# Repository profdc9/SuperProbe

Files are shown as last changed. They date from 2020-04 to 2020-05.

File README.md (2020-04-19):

This is a KiCad implementation of Carlson's Superprobe by Daniel L. Marks, KW4TI.

It integrates the probe into the PCB by using the ground plane and vias to shield the probe.  The solder mask is left off of the area around the probe so that the probe can be taped over with copper or aluminum tape for extra shielding.

The PCB design is distributed under the Creative Commons Shared Alike Attribution (CC-BY-SA 4.0) license.

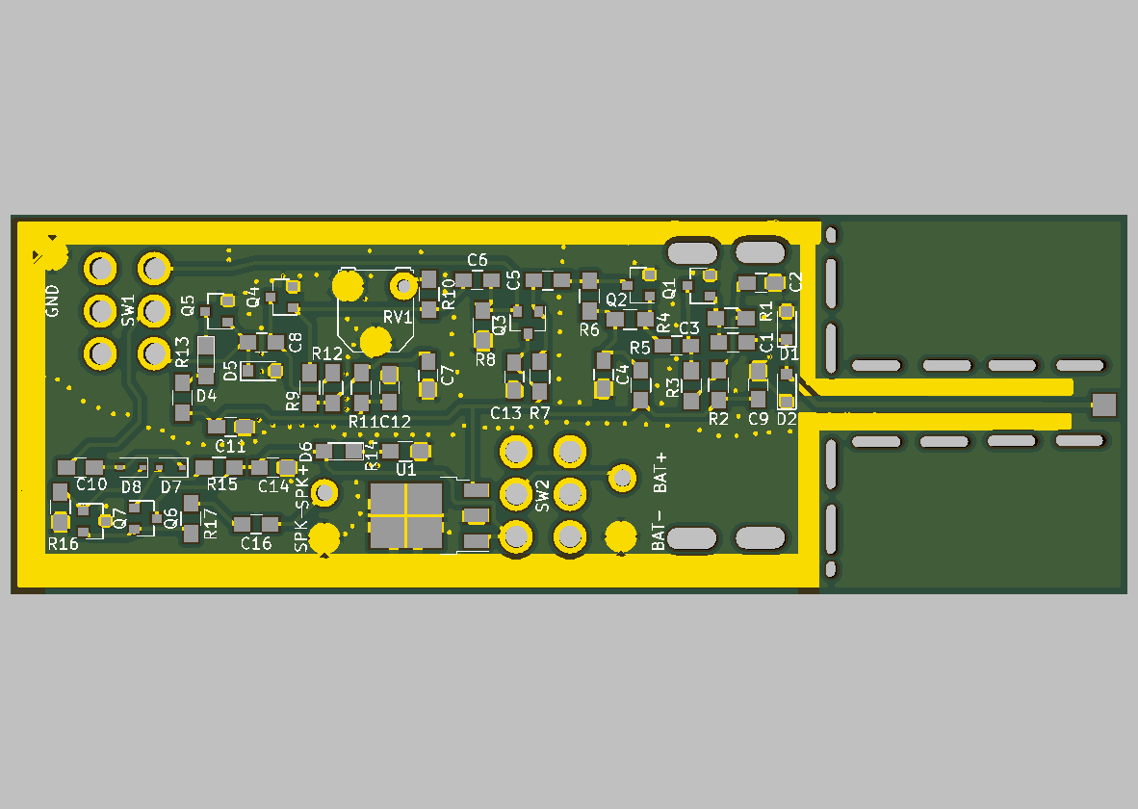
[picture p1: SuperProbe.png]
x


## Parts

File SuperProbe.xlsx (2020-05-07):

Comment | Designator | Footprint | LCSC
10 nF | C1,C3 | Capacitors_SMD:C_0805_HandSoldering | C1710
22 uF | C2,C4,C7,C16 | Capacitors_SMD:C_0805_HandSoldering | C45783
100 nF | C5,C6,C10 | Capacitors_SMD:C_0805_HandSoldering | C49678
330 pF | C8 | Capacitors_SMD:C_0805_HandSoldering | C51207
1 uF | C9,C12,C13,C11,C14 | Capacitors_SMD:C_0805_HandSoldering | C28323
1N4148WS | D1,D2 | Diodes_SMD:D_SOD-323_HandSoldering | C2128
LRB751V | D3,D5 | Diodes_SMD:D_SOD-323_HandSoldering | C131730
LED | D4,D6 | LEDs:LED_0805_HandSoldering | C34499
1N4148WS | D7,D8 | Diodes_SMD:D_SOD-323 | C2128
Conn_01x01 | J1,J16,J18,J19,J17,J24 | SuperProbe:PadHole
Conn_01x01 | J2,J3,J6,J7,J4,J5,J8,J9,J10,J11,J14,J15,J12,J13,J20,J21,J23,J22 | SuperProbe:BigSlot
MMBT3904 | Q1,Q2,Q3,Q4,Q5 | TO_SOT_Packages_SMD:SOT-23 | C20526
SS8050 | Q6 | TO_SOT_Packages_SMD:SOT-23 | C2150
SS8550 | Q7 | TO_SOT_Packages_SMD:SOT-23 | C8542
2M2 | R1,R4,R7,R9 | Resistors_SMD:R_0805_HandSoldering | C26113
330k | R10 | Resistors_SMD:R_0805_HandSoldering | C17629
10k | R16,R15 | Resistors_SMD:R_0805_HandSoldering | C17414
47R | R17 | Resistors_SMD:R_0805_HandSoldering | C17714
1k | R2,R5,R11,R13,R14 | Resistors_SMD:R_0805_HandSoldering | C17513
15k | R3,R6,R12 | Resistors_SMD:R_0805_HandSoldering | C17475
2k7 | R8 | Resistors_SMD:R_0805_HandSoldering | C17530
100k | RV1 | Potentiometers:Potentiometer_Triwood_RM-065
SW_SPDT | SW1 | SuperProbe:DPDTsmallswitch
SW_DPDT_x2 | SW2 | SuperProbe:DPDTsmallswitch
LM78M05_TO252 | U1 | TO_SOT_Packages_SMD:TO-252-3_TabPin2 | C58069

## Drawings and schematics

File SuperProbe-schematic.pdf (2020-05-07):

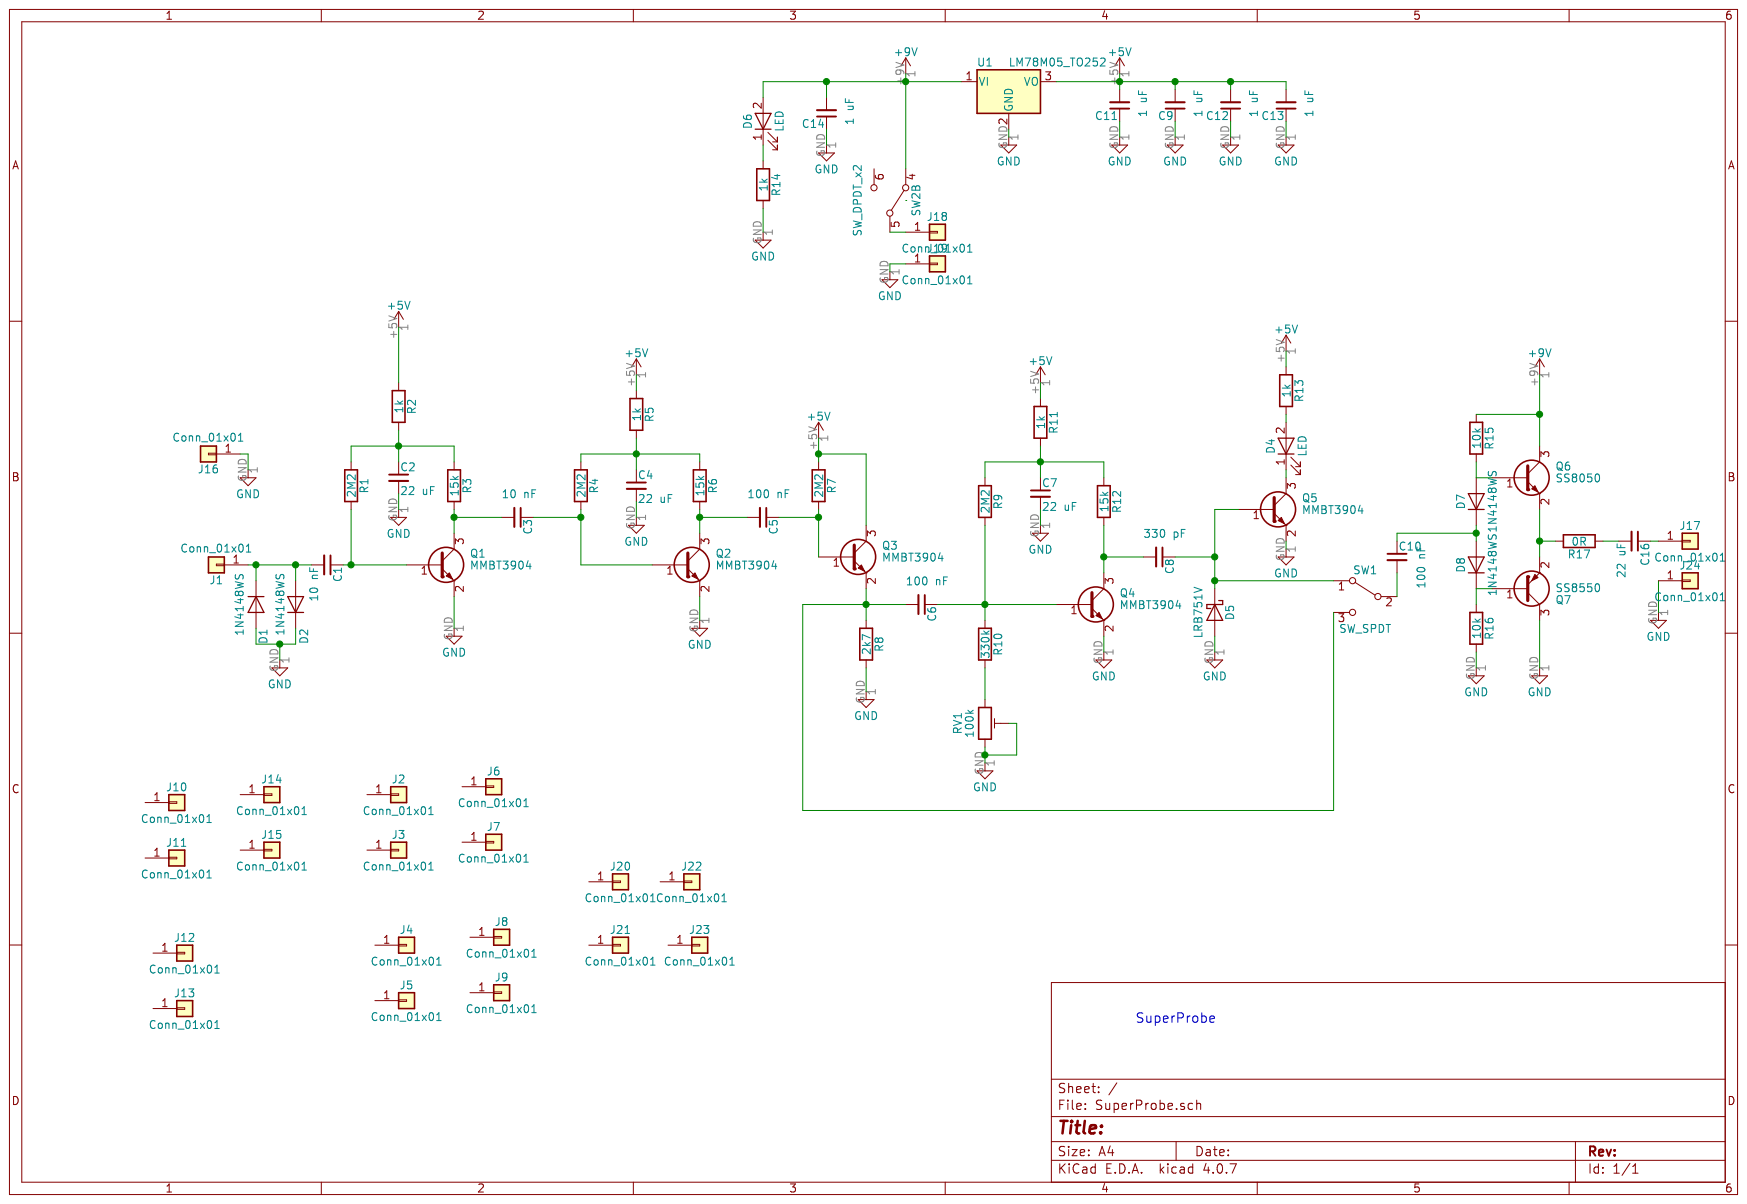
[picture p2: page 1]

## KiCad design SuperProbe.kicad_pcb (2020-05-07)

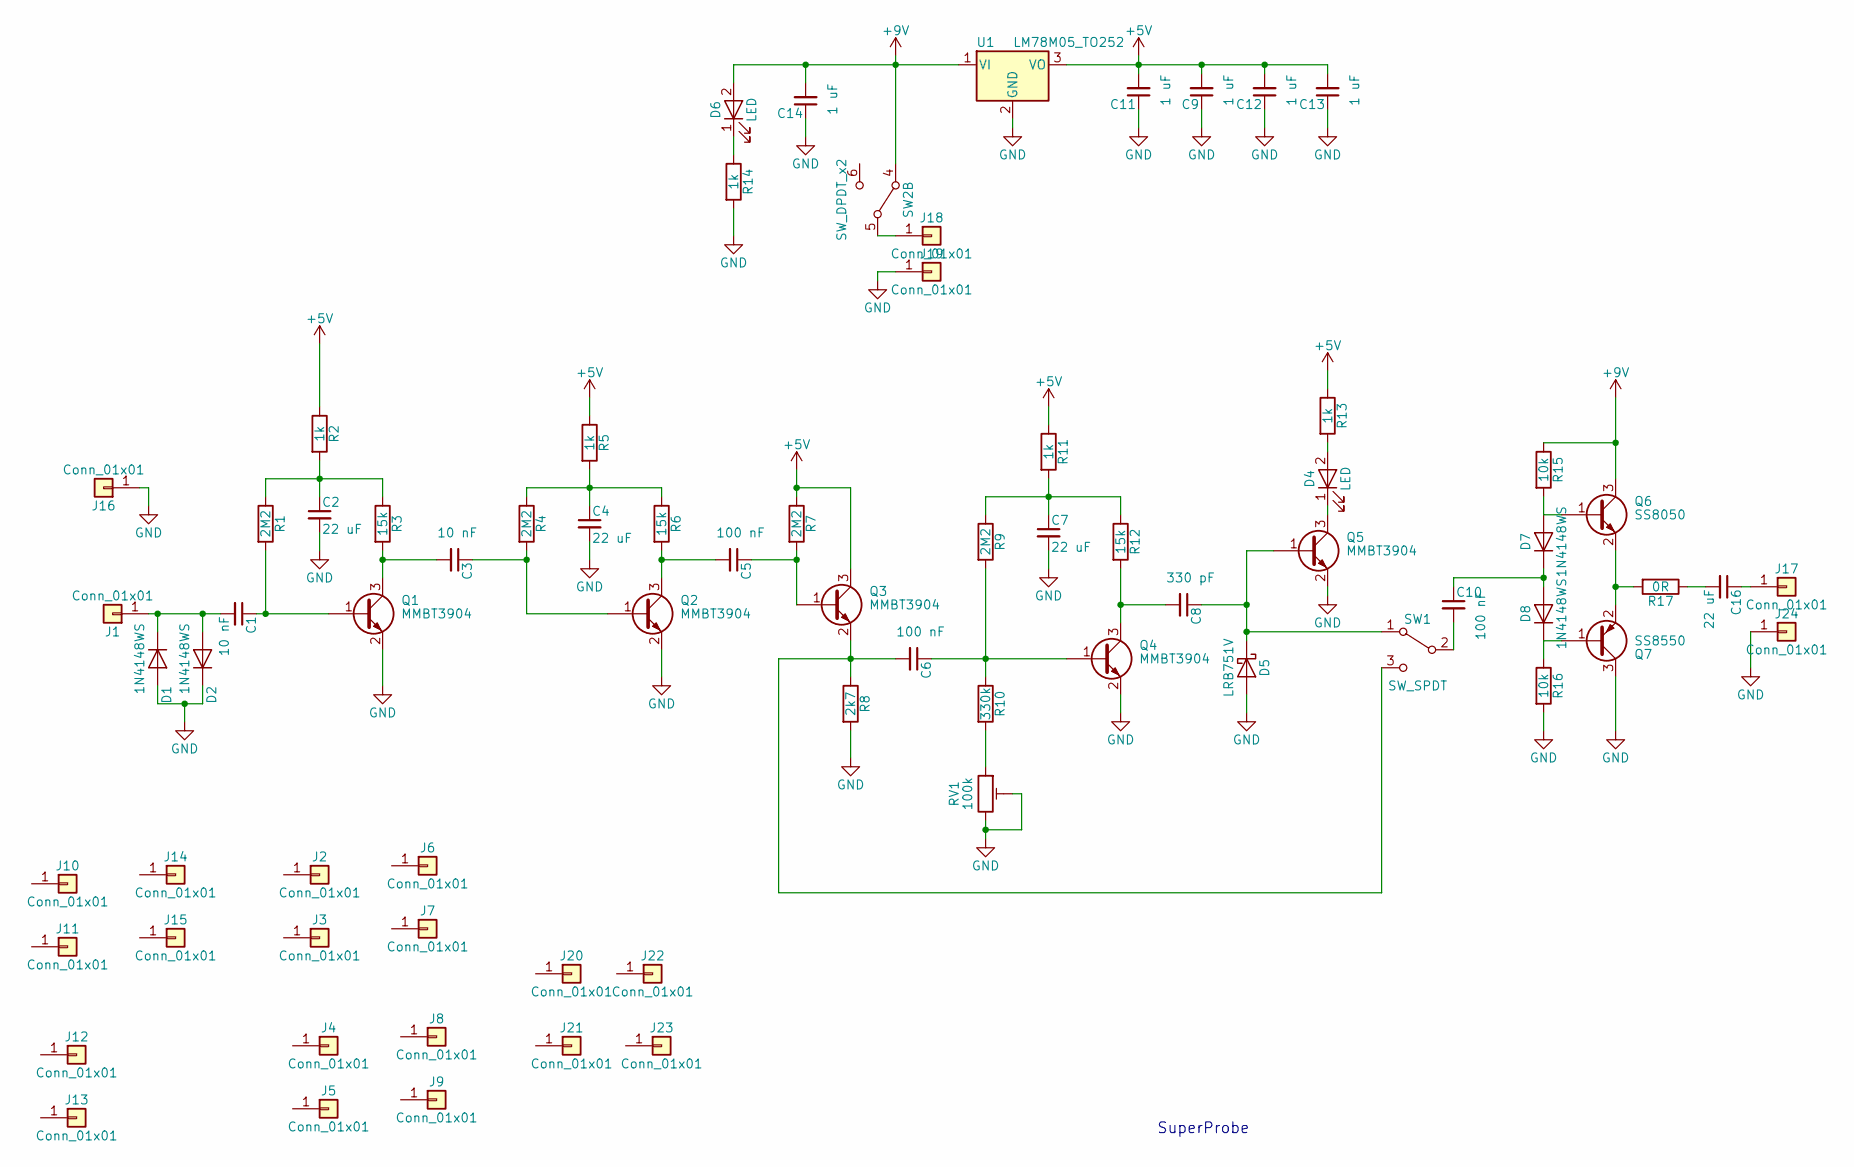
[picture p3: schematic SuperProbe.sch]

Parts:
C1, C3: 10 nF; C_0805_HandSoldering; LCSC C1710
C2, C4, C7, C16: 22 uF; C_0805_HandSoldering; LCSC C45783
C5, C10: 100 nF; C_0805_HandSoldering; LCSC C49678
C6: 100 nF; C_0805_HandSoldering
C8: 330 pF; C_0805_HandSoldering; LCSC C51207
C9, C11, C12, C13, C14: 1 uF; C_0805_HandSoldering; LCSC C28323
D1, D2: 1N4148WS; D_SOD-323_HandSoldering; LCSC C2128
D4: LED; LED_0805_HandSoldering; LCSC C34499
D5: LRB751V; D_SOD-323_HandSoldering; LCSC C131730
D6: LED; LED_0805_HandSoldering; LCSC C2296
D7, D8: 1N4148WS; D_SOD-323; LCSC C2128
J1, J16, J17, J18, J19, J24: Conn_01x01; PadHole
J2, J3, J4, J5, J6, J7, J8, J9, J10, J11, J12, J13, J14, J15, J20, J21, J22, J23: Conn_01x01; BigSlot
Q1, Q2, Q3, Q4, Q5: MMBT3904; SOT-23; LCSC C20526
Q6: SS8050; SOT-23; LCSC C2150
Q7: SS8550; SOT-23; LCSC C8542
R1, R4, R7, R9: 2M2; R_0805_HandSoldering; LCSC C26113
R2, R5, R11, R13, R14: 1k; R_0805_HandSoldering; LCSC C17513
R3, R6, R12: 15k; R_0805_HandSoldering; LCSC C17475
R8: 2k7; R_0805_HandSoldering; LCSC C17530
R10: 330k; R_0805_HandSoldering; LCSC C17629
R15, R16: 10k; R_0805_HandSoldering; LCSC C17414
R17: 0R; R_0805_HandSoldering; LCSC C17477
RV1: 100k; Potentiometer_Triwood_RM-065
SW1: SW_SPDT; DPDTsmallswitch
SW2: SW_DPDT_x2; DPDTsmallswitch
U1: LM78M05_TO252; TO-252-3_TabPin2; LCSC C58069

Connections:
+5V: C9.2, C11.2, C12.2, C13.2, Q3.3 (C), R2.1, R5.1, R7.1, R11.1, R13.1, U1.3 (VO)
+9V: C14.2, D6.2 (A), Q6.3 (C), R15.1, SW2.4 (A), U1.1 (VI)
GND: C2.2, C4.2, C7.2, C9.1, C11.1, C12.1, C13.1, C14.1, D1.2 (A), D2.1 (K), D5.2 (A), J16.1, J19.1, J24.1, Q1.2 (E), Q2.2 (E), Q4.2 (E), Q5.2 (E), Q7.3 (C), R8.2, R14.2, R16.2, RV1.2, RV1.3, U1.2 (GND)
unnamed: C1.1, Q1.1 (B), R1.2
unnamed: C1.2, D1.1 (K), D2.2 (A), J1.1
unnamed: C2.1, R1.1, R2.2, R3.1
unnamed: C3.1, Q2.1 (B), R4.2
unnamed: C3.2, Q1.3 (C), R3.2
unnamed: C4.1, R4.1, R5.2, R6.1
unnamed: C5.1, Q3.1 (B), R7.2
unnamed: C5.2, Q2.3 (C), R6.2
unnamed: C6.1, Q4.1 (B), R9.2, R10.1
unnamed: C6.2, Q3.2 (E), R8.1, SW1.3 (C)
unnamed: C7.1, R9.1, R11.2, R12.1
unnamed: C8.1, D5.1 (K), Q5.1 (B), SW1.1 (A)
unnamed: C8.2, Q4.3 (C), R12.2
unnamed: C10.1, D7.1 (K), D8.2 (A)
unnamed: C10.2, SW1.2 (B)
unnamed: C16.1, J17.1
unnamed: C16.2, R17.1
unnamed: D4.1 (K), Q5.3 (C)
unnamed: D4.2 (A), R13.2
unnamed: D6.1 (K), R14.1
unnamed: D7.2 (A), Q6.1 (B), R15.2
unnamed: D8.1 (K), Q7.1 (B), R16.1
unnamed: J18.1, SW2.5 (B)
unnamed: Q6.2 (E), Q7.2 (E), R17.2
unnamed: R10.2, RV1.1

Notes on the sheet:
SuperProbe

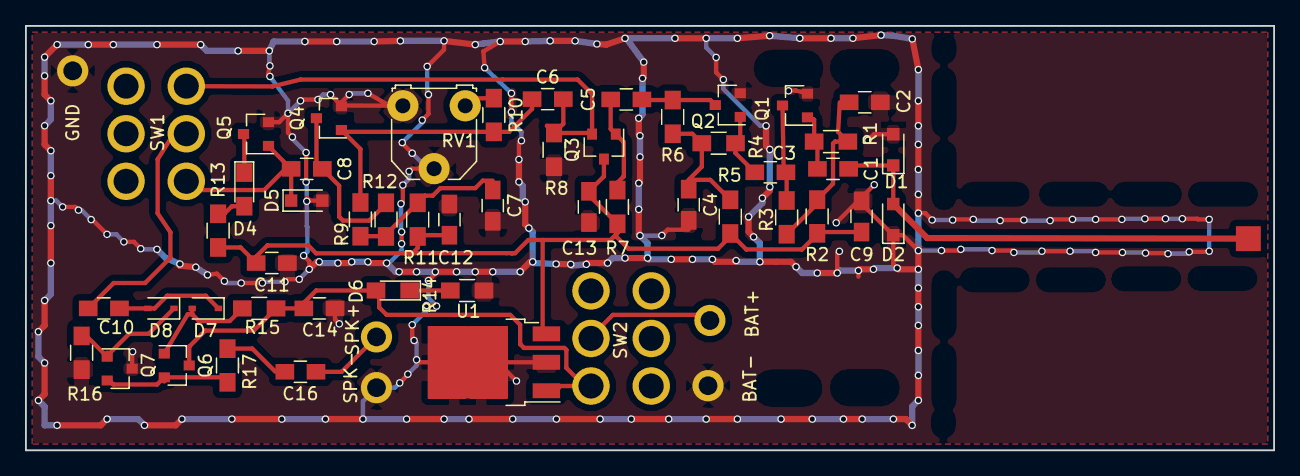
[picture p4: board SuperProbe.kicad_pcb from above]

Board: 2 copper layers, 100.0 x 34.0 mm, 74 parts (0 on the bottom side), 28 nets.

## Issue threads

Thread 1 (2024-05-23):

D3 missing

gamerpaddy, 2024-05-23:
BOM has it but schematic doesnt.

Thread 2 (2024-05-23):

Volume output too low on 8ohm speaker

gamerpaddy, 2024-05-23:
built one, but its barely audible when using a 8ohm speaker.

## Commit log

2020-04-19 Committed all files
    [SuperProbe.sch]
2020-04-19 Removed solder mask from ring around the board
    [SuperProbe-B.Cu.gbr, SuperProbe-B.Mask.gbr, SuperProbe-B.SilkS.gbr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]
2020-04-19 Added pcb kicad
    [SuperProbe.kicad_pcb]
2020-04-19 Before getting rid of the coin cells
    [SuperProbe-B.Cu.gbr, SuperProbe-B.Mask.gbr, SuperProbe-B.SilkS.gbr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]
2020-04-19 Uses 9 volt battery and board shrink
    [SuperProbe-B.Cu.gbr, SuperProbe-B.Mask.gbr, SuperProbe-B.SilkS.gbr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]
2020-04-23 Cleaned up the board slightly
    [SuperProbe-B.Cu.gbr, SuperProbe-B.Mask.gbr, SuperProbe-B.SilkS.gbr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]
2020-04-23 Added PadHole.kicad_mod
2020-05-07 Eliminated unneeded diode
    [SuperProbe-B.Cu.gbr, SuperProbe-B.Mask.gbr, SuperProbe-B.SilkS.gbr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]
